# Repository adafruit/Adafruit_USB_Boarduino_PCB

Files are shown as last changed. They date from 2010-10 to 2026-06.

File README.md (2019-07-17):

# USB Boarduino (Arduino compatible) Kit w/ATmega328 - v2.0

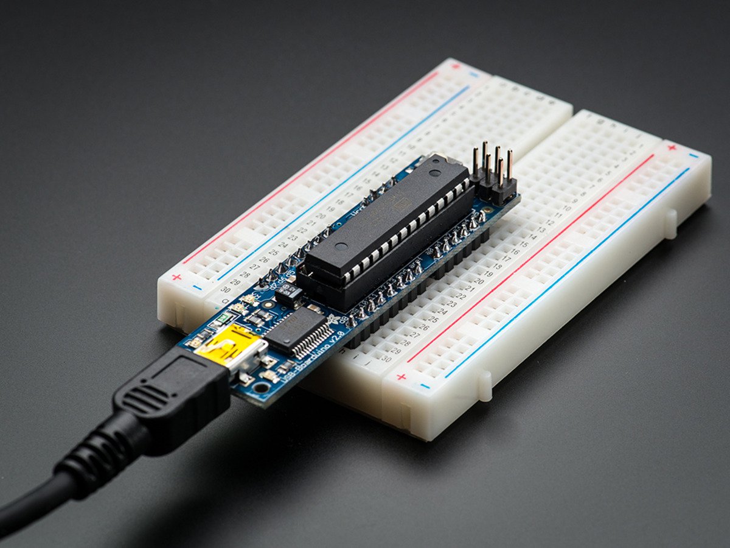
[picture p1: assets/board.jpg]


If you've ever struggled to use a solderless breadboard with an Arduino, you understand how frustrating it can be!

This development board acts just like an Arduino, and works with the latest Arduino software. For many projects it can even be preferable! The kit includes all parts necessary, the assembly is straightforward and well documented, using just a soldering iron anyone can complete it within 10 or 15 minutes.

This version of the Boarduino does not have a DC jack. That means you __can't__ use a 9V adapter or battery holder with it (unless you build a 5V power supply). However __it does have USB built in__ and you can power your project or USB or by using a [Mintyboost kit](https://www.adafruit.com/products/14) (which takes 2 AA batteries).

Specifications:

- Designed to plug into a breadboard for easy prototyping
- Petite size, only 2.75" x 0.8" (75mm x 20mm)
- All 'standard' pins are brought out - Digital 0-13, Analog 0-5, ARef, 5V, 3V, Ground, and Reset
- Chip comes pre-programmed with a "no-wait" Arduino bootloader ([Read more here](https://learn.adafruit.com/arduino-tips-tricks-and-techniques/bootloader))
- 4 LEDs! There's a green power-good LED, a red "pin 13" LED (just like the Arduino), and a pair of RX and TX indicator LEDs for debugging the serial connection
- Nearly-all-surfacemount design. We left the chip as through-hole to make it easier to upgrade and repair. All surface mount parts are pre-assembled and tested.
- Reset button
- ATmega328P, running at 16.00 MHz, just like all Arduinos
- 6-pin standard ICSP header
- USB miniB jack
- 500mA fuse protects your computer's USB port from overcurrent
- Auto-reset capability

There's a lot more to read at the [USB Boarduino webpage](https://learn.adafruit.com/boarduino-kits).

### License

Adafruit invests time and resources providing this open source design, please support Adafruit and open-source hardware by purchasing products from [Adafruit](https://www.adafruit.com)!

Designed by Limor Fried/Ladyada for Adafruit Industries.

Creative Commons Attribution/Share-Alike, all text above must be included in any redistribution. See license.txt for additional details.

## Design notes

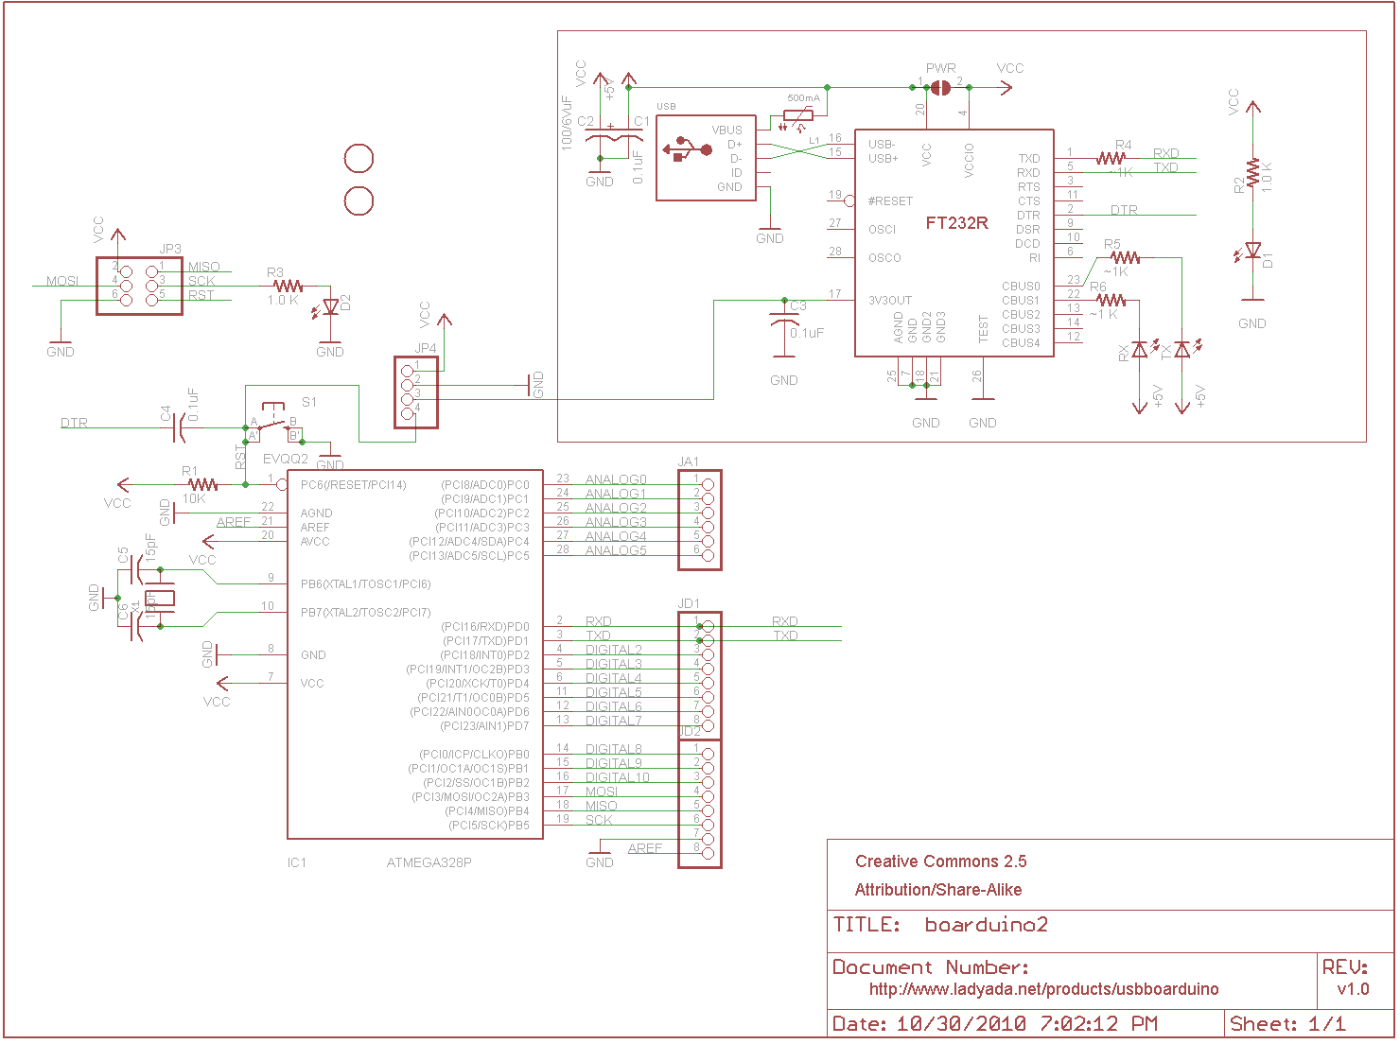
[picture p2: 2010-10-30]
usbboarduino20sch.png

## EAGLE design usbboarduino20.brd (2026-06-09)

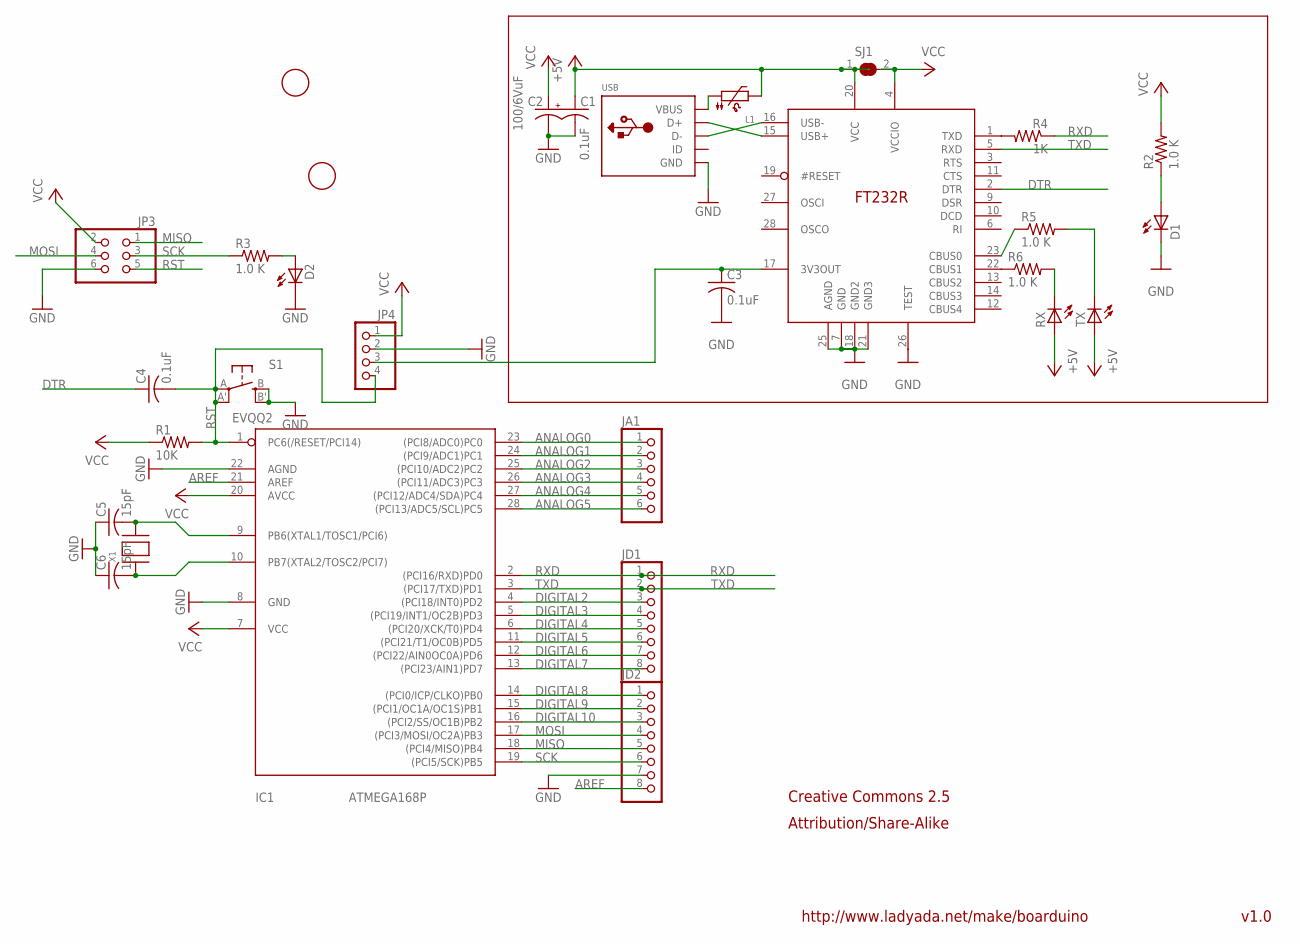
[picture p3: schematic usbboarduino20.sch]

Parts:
C1, C3, C4: 0.1uF; C0805K
C2: 100/6VuF; B/3528-21R
C5, C6: 15pF; C0805K
D1: LEDCHIPLED_0805; CHIPLED_0805
D2: Green; CHIPLED_0805
IC1: ATMEGA168P; DIL28/3
IC2: FT232R; TSSOP28
JA1: PINHD-1X6CB; 1X06-CLEANBIG
JD1, JD2: PINHD-1X8CLEANBIG; 1X08-CLEANBIG
JP3: PINHD-2X3; 2X03
JP4: PINHD-1X4CB; 1X04-CB
L1: PTC1206; 1206
R1: 10K; R0805
R2, R3, R5, R6: 1.0 K; R0805
R4: 1K; R0805
RX: Green; CHIPLED_0805
S1: EVQQ2; EVQ-Q2
SJ1: SOLDERJUMPERREFLOW; SOLDERJUMPER_REFLOW
TX: Green; CHIPLED_0805
U$1, U$2: FIDUCIAL; FIDUCIAL_1MM
USB: USBMINIB; USB-MINIB
X1: XTALNX5032; NX5032

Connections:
3V: C3.1, IC2.17 (3V3OUT), JP4.3
+5V: C1.1, IC2.20 (VCC), L1.2, RX.A, SJ1.1, TX.A
ANALOG0: IC1.23 ((PCI8/ADC0)PC0), JA1.1
ANALOG1: IC1.24 ((PCI9/ADC1)PC1), JA1.2
ANALOG2: IC1.25 ((PCI10/ADC2)PC2), JA1.3
ANALOG3: IC1.26 ((PCI11/ADC3)PC3), JA1.4
ANALOG4: IC1.27 ((PCI12/ADC4/SDA)PC4), JA1.5
ANALOG5: IC1.28 ((PCI13/ADC5/SCL)PC5), JA1.6
AREF: IC1.21 (AREF), JD2.8
DIGITAL2: IC1.4 ((PCI18/INT0)PD2), JD1.3
DIGITAL3: IC1.5 ((PCI19/INT1/OC2B)PD3), JD1.4
DIGITAL4: IC1.6 ((PCI20/XCK/T0)PD4), JD1.5
DIGITAL5: IC1.11 ((PCI21/T1/OC0B)PD5), JD1.6
DIGITAL6: IC1.12 ((PCI22/AIN0OC0A)PD6), JD1.7
DIGITAL7: IC1.13 ((PCI23/AIN1)PD7), JD1.8
DIGITAL8: IC1.14 ((PCI0/ICP/CLKO)PB0), JD2.1
DIGITAL9: IC1.15 ((PCI1/OC1A/OC1S)PB1), JD2.2
DIGITAL10: IC1.16 ((PCI2/SS/OC1B)PB2), JD2.3
DTR: C4.1, IC2.2 (DTR)
GND: C1.2, C2.-, C3.2, C5.1, C6.1, D1.C, D2.C, IC1.8 (GND), IC1.22 (AGND), IC2.7 (GND), IC2.18 (GND2), IC2.21 (GND3), IC2.25 (AGND), IC2.26 (TEST), JD2.7, JP3.6, JP4.2, S1.B (S), S1.B' (S1), USB.GND
MISO: IC1.18 ((PCI4/MISO)PB4), JD2.5, JP3.1
MOSI: IC1.17 ((PCI3/MOSI/OC2A)PB3), JD2.4, JP3.4
unnamed: C5.2, IC1.9 (PB6(XTAL1/TOSC1/PCI6)), X1.P$2
unnamed: C6.2, IC1.10 (PB7(XTAL2/TOSC2/PCI7)), X1.P$1
unnamed: D1.A, R2.1
unnamed: D2.A, R3.2
unnamed: IC2.15 (USB+), USB.D+
unnamed: IC2.16 (USB-), USB.D-
unnamed: IC2.1 (TXD), R4.2
unnamed: L1.1, USB.VBUS
unnamed: R6.2, RX.C
unnamed: R5.2, TX.C
unnamed: IC2.22 (CBUS1), R6.1
unnamed: IC2.23 (CBUS0), R5.1
RST: C4.2, IC1.1 (PC6(/RESET/PCI14)), JP3.5, JP4.4, R1.2, S1.A, S1.A' (P1)
RXD: IC1.2 ((PCI16/RXD)PD0), JD1.1, R4.1
SCK: IC1.19 ((PCI5/SCK)PB5), JD2.6, JP3.3, R3.1
TXD: IC1.3 ((PCI17/TXD)PD1), IC2.5 (RXD), JD1.2
VCC: C2.+, IC1.7 (VCC), IC1.20 (AVCC), IC2.4 (VCCIO), JP3.2, JP4.1, R1.1, R2.2, SJ1.2

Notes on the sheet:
v1.0
http://www.ladyada.net/make/boarduino
Creative Commons 2.5
Attribution/Share-Alike

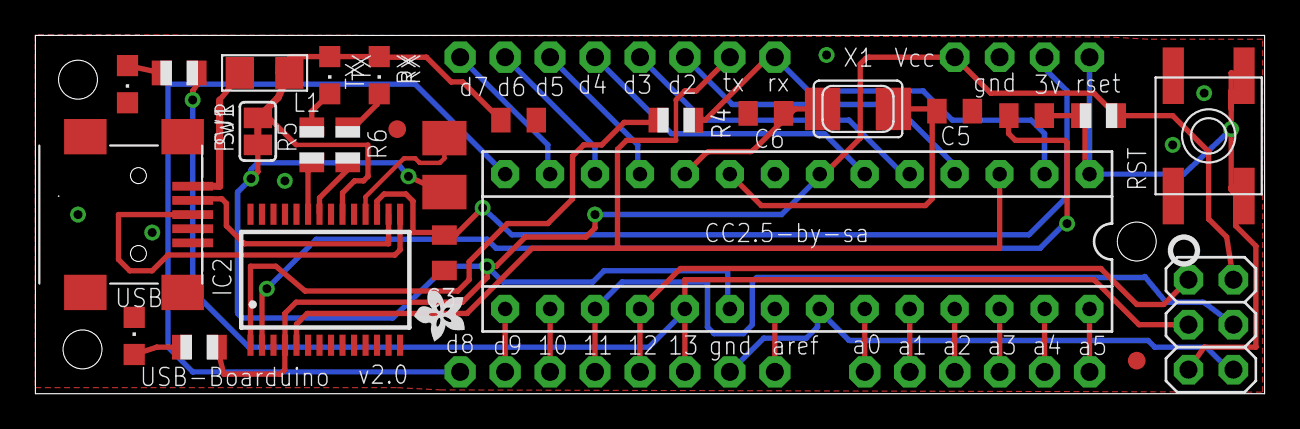
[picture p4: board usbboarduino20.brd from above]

Board: 2 copper layers, 69.4 x 20.2 mm, 31 parts (0 on the bottom side), 39 nets.

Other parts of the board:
U$3: ADAFRUIT200MIL
